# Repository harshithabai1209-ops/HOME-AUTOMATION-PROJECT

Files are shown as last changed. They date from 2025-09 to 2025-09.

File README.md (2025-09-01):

# HOME-AUTOMATION-PROJECT(PCB DESIGN)

🏠 IoT-Based Home Automation System
📌 Overview

This project is a Wi-Fi-enabled smart home automation system built using ESP32/ESP8266, IoT protocols, and a custom PCB designed in KiCad.
It allows users to control home appliances (lights, fans, etc.) remotely through a mobile/web dashboard and integrates sensors (temperature, motion, gas, light) for intelligent automation.

🚀 Features

Remote control of AC appliances (fan, light, etc.)

Wi-Fi-based communication (ESP32/ESP8266)

Cloud / MQTT / Blynk / Local server support

Real-time sensor data monitoring

Relay driver circuit with isolation for AC safety

Custom PCB designed in KiCad with proper AC/DC isolation

🛠️ Hardware Components

ESP32 / ESP8266 NodeMCU – Wi-Fi microcontroller

Relay Module (5V/3.3V) – Switching AC loads

DHT11/DHT22 – Temperature & Humidity sensor

PIR Sensor – Motion detection

LDR – Light sensing

MQ-2 Gas Sensor – Safety monitoring

Power Supply – 5V regulated (AMS1117 or buck converter)

Optocoupler & Fuse – Protection for relay section

📐 PCB Design (KiCad)

Designed using KiCad EDA

Separate AC and DC sections for safety

Minimum 3–6 mm isolation gap between high-voltage and low-voltage traces

Solid ground planes for noise reduction

Gerber files generated for PCB manufacturing

⚙️ Software / Firmware

Developed using Arduino IDE / ESP-IDF

Supports:

MQTT (Mosquitto / Cloud broker)

Blynk / ThingsBoard / Custom Web UI

Example firmware features:

Control appliances via mobile app

Read sensor values & push to dashboard

Automation rules (e.g., auto fan ON if temperature > 30°C)

🔌 Circuit Block Diagram
        +-------------------+       +-------------+
        |   ESP32/ESP8266   |------>|  Relay Unit |----> AC Load (Fan/Light)
        +-------------------+       +-------------+
                 |                          |
            +----------+              +----------+
            |  Sensors |              |  Power   |
            +----------+              +----------+

📂 Project Structure
Home-Automation-IoT/
│── hardware/
│   ├── schematics/        # KiCad schematic files
│   ├── pcb-layout/        # PCB design files
│   └── gerbers/           # Manufacturing files
│
│── firmware/
│   ├── main.ino           # Arduino code
│   └── config.h           # Wi-Fi, MQTT, API keys
│
│── docs/
│   ├── README.md          # Project documentation
│   └── images/            # Circuit & PCB renders

🧩 Applications

Smart home & IoT automation

Energy-efficient lighting & appliances

Remote healthcare monitoring (with sensors)

Industrial automation (extended use case)

⚠️ Safety Note

⚡ Caution: This project involves AC mains (230V/110V). Handle with extreme care.
Use proper isolation, fuses, and enclosures while testing.

📖 Future Enhancements

Voice assistant integration (Alexa, Google Assistant)

Mobile app with Flutter/React Native

AI-based predictive automation

Integration with solar energy systems

✨ Made with ❤️ using Embedded Systems + IoT + KiCad

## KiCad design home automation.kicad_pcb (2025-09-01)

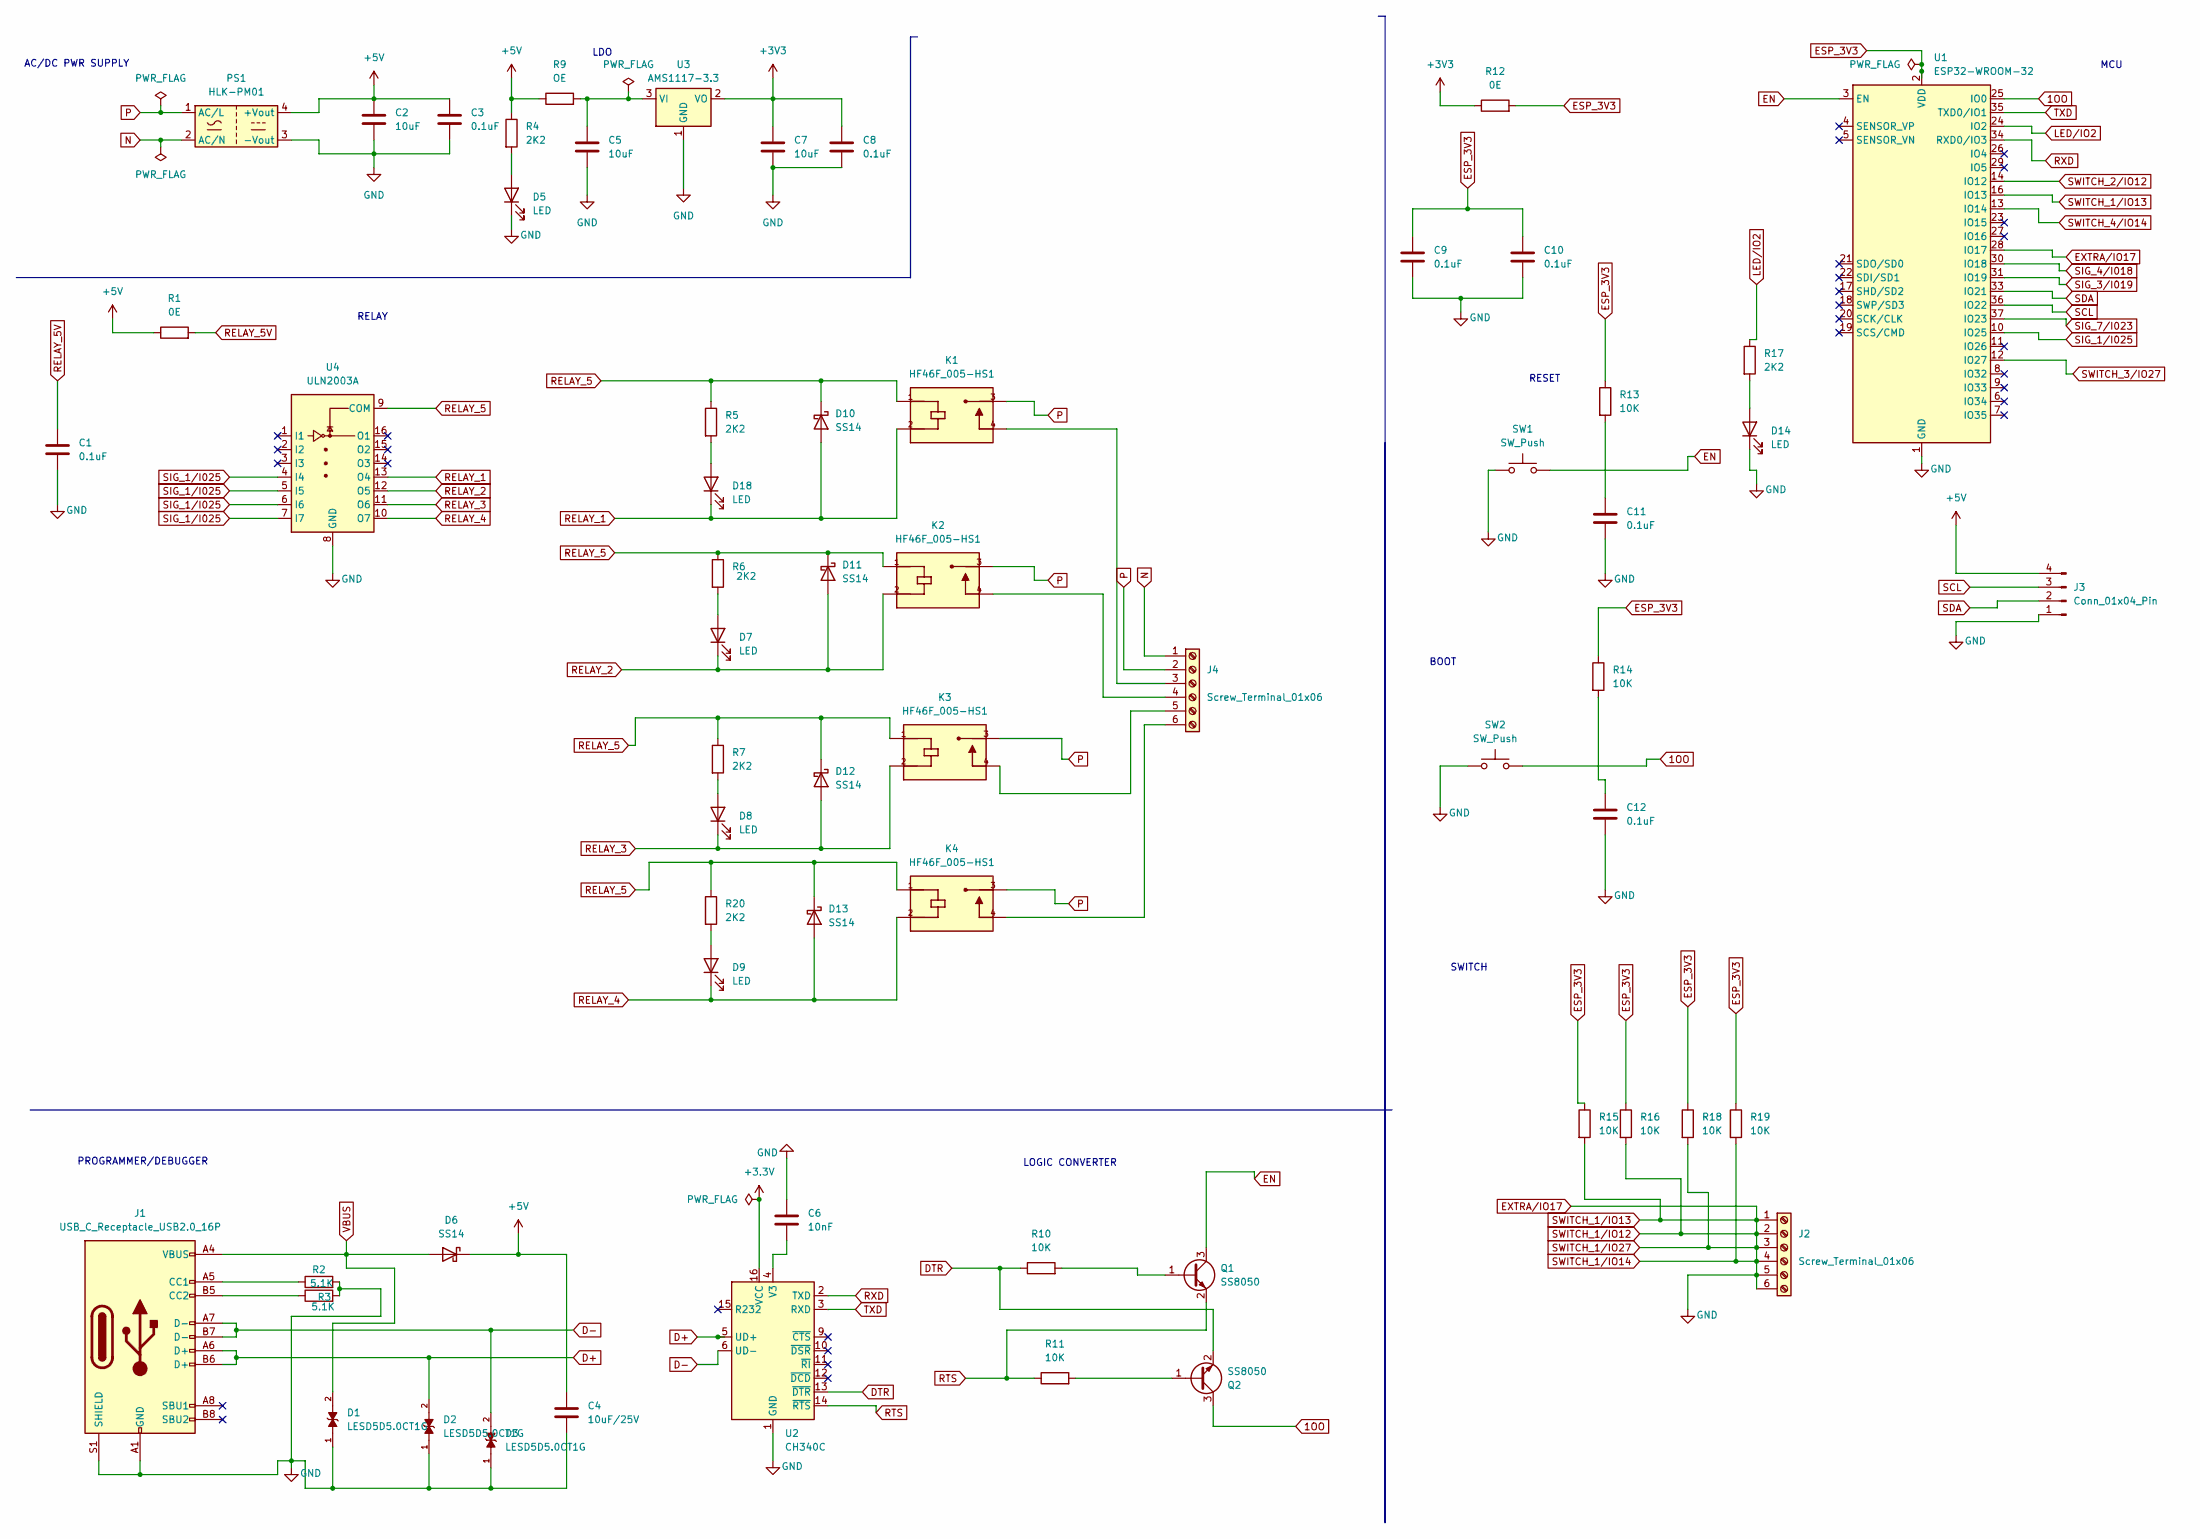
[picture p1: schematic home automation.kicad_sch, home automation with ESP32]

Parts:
C1, C3, C8, C9, C10, C11, C12: 0.1uF; C_0603_1608Metric
C2, C5, C7: 10uF; C_1206_3216Metric
C4: 10uF/25V; C_1206_3216Metric
C6: 10nF; C_1206_3216Metric
D1, D2, D3: LESD5D5.0CT1G; TVS_LESD5D5.0CT1G; PARTREV O
D5, D7, D8, D9, D14, D18: LED; LED_0603_1608Metric
D6, D10, D11, D12, D13: SS14; D_SMA
J1: USB_C_Receptacle_USB2.0_16P; USB_C_Receptacle_HCTL_HC-TYPE-C-16P-01A
J2, J4: Screw_Terminal_01x06; TerminalBlock_bornier-6_P5.08mm
J3: Conn_01x04_Pin; PinHeader_1x04_P2.54mm_Vertical
K1, K2, K3, K4: HF46F_005-HS1; RELAY_HF46F_005-HS1; PARTREV 1.00
PS1: HLK-PM01; Converter_ACDC_Hi-Link_HLK-PMxx
Q1, Q2: SS8050; SOT-23
R1, R12: 0E; R_0603_1608Metric
R2, R3: 5.1K; R_0603_1608Metric
R4, R5, R6, R7, R17, R20: 2K2; R_0603_1608Metric
R9: OE; R_0603_1608Metric
R10, R11, R13, R14, R15, R16, R18, R19: 10K; R_0603_1608Metric
SW1, SW2: SW_Push; SW_Push_SPST_NO_Alps_SKRK
U1: ESP32-WROOM-32
U2: CH340C; SOIC-16_3.9x9.9mm_P1.27mm
U3: AMS1117-3.3; SOT-223-3_TabPin2
U4: ULN2003A; SOIC-16_3.9x9.9mm_P1.27mm

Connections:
1OO: Q2.3 (C), SW2.2, U1.25 (IO0)
+3.3V: U2.16 (VCC)
+3V3: C7.1, C8.1, R12.1, U3.2 (VO)
+5V: C2.1, C3.1, C4.1, D6.1 (K), J3.4, PS1.4 (+Vout), R1.1, R4.1, R9.1
D+: D2.2, J1.A6 (D+), J1.B6 (D+), U2.5 (UD+)
D-: D3.2, J1.A7 (D-), J1.B7 (D-), U2.6 (UD-)
DTR: Q2.2 (E), R10.1, U2.13 (~DTR)
EN: Q1.3 (C), SW1.2, U1.3 (EN)
ESP_3V3: C9.1, C10.1, R12.2, R13.1, R14.1, R15.1, R16.1, R18.1, R19.1, U1.2 (VDD)
EXTRA/IO17: C1.2, C2.2, C3.2, C4.2, C5.2, C6.2, C7.2, C8.2, C9.2, C10.2, C11.2, C12.2, D1.1, D2.1, D3.1, D5.1 (K), D14.1 (K), J1.A1 (GND), J1.A12 (GND), J1.B1 (GND), J1.B12 (GND), J1.S1 (SHIELD), J2.1, J2.2, J2.3, J2.4, J2.5, J2.6, J3.1, PS1.3 (-Vout), R2.2, R3.2, R15.2, R16.2, R18.2, R19.2, SW1.1, SW2.1, U1.1 (GND), U1.15 (GND), U1.16 (IO13), U1.28 (IO17), U1.38 (GND), U1.39 (GND), U2.1 (GND), U3.1 (GND), U4.8 (GND)
LED/IO2: R17.1, U1.24 (IO2)
N: J4.1, PS1.2 (AC/N)
unnamed: C11.1, R13.2
unnamed: C12.1, R14.2
unnamed: D5.2 (A), R4.2
unnamed: D7.2 (A), R6.2
unnamed: D8.2 (A), R7.2
unnamed: D9.2 (A), R20.2
unnamed: D14.2 (A), R17.2
unnamed: D18.2 (A), R5.2
unnamed: J1.A5 (CC1), R2.1
unnamed: J1.B5 (CC2), R3.1
unnamed: J4.3, K1.4
unnamed: J4.4, K2.4
unnamed: J4.5, K3.4
unnamed: J4.6, K4.4
unnamed: Q1.1 (B), R10.2
unnamed: Q2.1 (B), R11.2
unnamed: C6.1, U2.4 (V3)
unnamed: C5.1, R9.2, U3.3 (VI)
P: J4.2, K1.3, K2.3, K3.3, K4.3, PS1.1 (AC/L)
RELAY_1: D10.2 (A), D18.1 (K), K1.2, U4.13 (O4)
RELAY_2: D7.1 (K), D11.2 (A), K2.2, U4.12 (O5)
RELAY_3: D8.1 (K), D12.2 (A), K3.2, U4.11 (O6)
RELAY_4: D9.1 (K), D13.2 (A), K4.2, U4.10 (O7)
RELAY_5: D10.1 (K), D11.1 (K), D12.1 (K), D13.1 (K), K1.1, K2.1, K3.1, K4.1, R5.1, R6.1, R7.1, R20.1, U4.9 (COM)
RELAY_5V: C1.1, R1.2
RTS: Q1.2 (E), R11.1, U2.14 (~RTS)
RXD: U1.34 (RXD0/IO3), U2.2 (TXD)
SCL: J3.3, U1.36 (IO22)
SDA: J3.2, U1.33 (IO21)
SIG_1/I025: U1.10 (IO25), U4.4 (I4), U4.5 (I5), U4.6 (I6), U4.7 (I7)
SIG_3/I019: U1.31 (IO19)
SIG_4/I018: U1.30 (IO18)
SIG_7/I023: U1.37 (IO23)
SWITCH_2/IO12: U1.14 (IO12)
SWITCH_3/IO27: U1.12 (IO27)
SWITCH_4/IO14: U1.13 (IO14)
TXD: U1.35 (TXD0/IO1), U2.3 (RXD)
VBUS: D1.2, D6.2 (A), J1.A4 (VBUS), J1.A9 (VBUS), J1.B4 (VBUS), J1.B9 (VBUS)

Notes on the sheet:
AC/DC PWR SUPPLY
LDO
BOOT
RESET
RELAY
PROGRAMMER/DEBUGGER
LOGIC CONVERTER
MCU
SWITCH

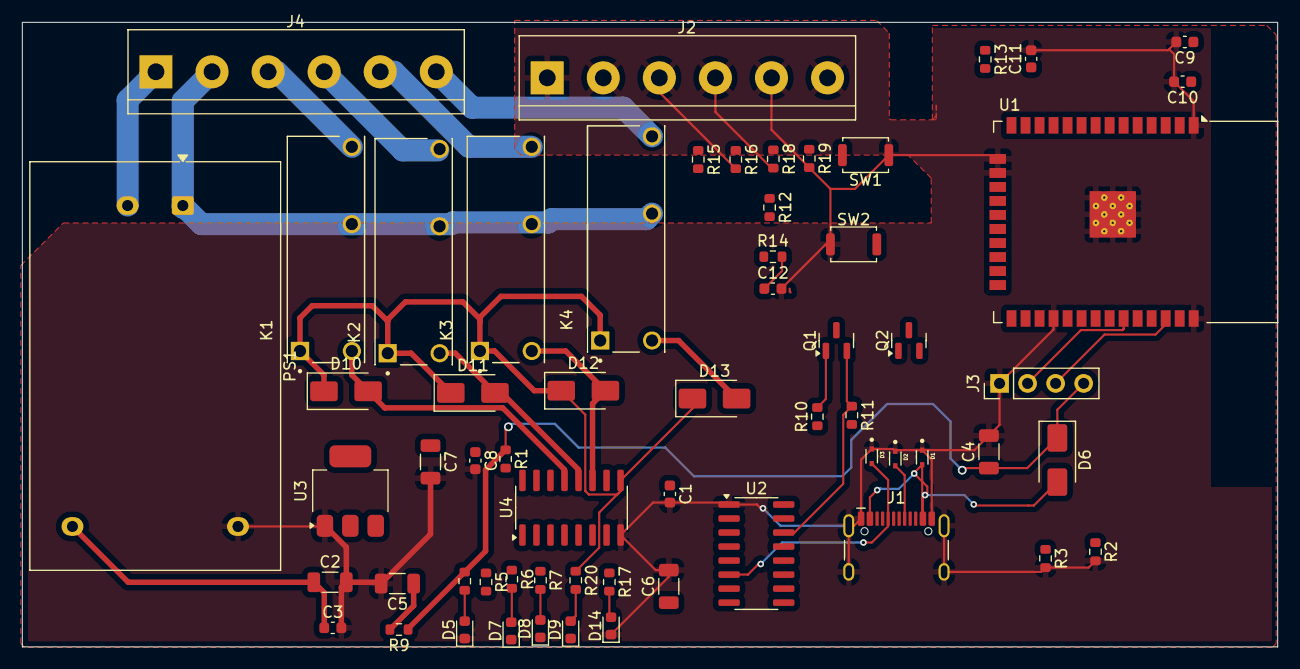
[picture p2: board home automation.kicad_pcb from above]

Board: 2 copper layers, 113.7 x 56.6 mm, 62 parts (1 on the bottom side), 43 nets.
